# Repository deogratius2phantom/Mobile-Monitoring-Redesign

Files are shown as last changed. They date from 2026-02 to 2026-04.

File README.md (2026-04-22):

# Mobile Air Quality Monitor - Hardware Design

A comprehensive PCB and CAD design for a mobile air quality monitoring system with GPS tracking and cellular connectivity.

## Documentation website

This repository now includes a GitHub Pages documentation site powered by **MkDocs Material**.

- Site source: `docs/`
- Site configuration: `mkdocs.yml`
- Deployment workflow: `.github/workflows/pages.yml`
- Python dependencies for docs work: `requirements-docs.txt`

Once GitHub Pages is enabled for this repository, the published site is expected at:

`https://deogratius2phantom.github.io/Mobile-Monitoring-Redesign/`

### Preview the docs locally

```powershell
python -m pip install -r requirements-docs.txt
python -m mkdocs serve
```

### Build the docs locally

```powershell
python -m mkdocs build --strict
```

## 📋 Project Overview

This repository contains the complete hardware design files for a portable air quality monitoring device. The system is designed to measure environmental air quality parameters while providing real-time GPS location tracking and cellular data transmission capabilities.

## 🔧 Key Features

- **GPS Tracking**: L80-M39 GPS module for precise location tracking
- **Cellular Connectivity**: SIM800L GSM/GPRS module for remote data transmission
- **Modular Design**: Includes daughter board for GPS module
- **Complete PCB Design**: Full KiCad project files with schematics and PCB layouts
- **3D Visualization**: STEP files for mechanical integration and enclosure design

## 📂 Repository Structure

```
├── 3D CAD/                          # 3D CAD files and models
├── L80 GPS daughter board v1/       # GPS module daughter board design files
├── Mobile Monitor Redesign-backups/ # Backup files for KiCad project
├── Mobile Monitor Redesign.kicad_pcb    # Main PCB layout file
├── Mobile Monitor Redesign.kicad_sch    # Main schematic file
├── Mobile Monitor Redesign.kicad_pro    # KiCad project file
├── Mobile Monitor Redesign.step         # 3D model of complete assembly
├── Mobile Monitor Redesign-top.pos      # Top side component positions
├── Mobile Monitor Redesign-bottom.pos   # Bottom side component positions
├── power.kicad_sch                      # Power supply schematic
├── L80-M39--3DModel-STEP-56544.STEP    # GPS module 3D model
├── SIM800L v10.step                     # SIM800L module 3D model
└── report.txt                           # Design report/notes
```

## 🛠️ Tools & Requirements

### Software
- **KiCad 6.0+**: For viewing and editing PCB/schematic files
- **CAD Software**: Any STEP-compatible viewer/editor for 3D models (e.g., FreeCAD, Fusion 360, SolidWorks)

### Hardware Components
- L80-M39 GPS Module
- SIM800L GSM/GPRS Module
- Air quality sensors (see schematic for specific models)
- Power management components (see power.kicad_sch)

## 🚀 Getting Started

### Cloning the Repository

You can clone this repository using either HTTPS or SSH:

#### Option 1: Clone with HTTPS
```bash
git clone https://github.com/deogratius2phantom/Mobile-Monitoring-Redesign.git
cd Mobile-Monitoring-Redesign
```

#### Option 2: Clone with SSH (Recommended for Contributors)
```bash
git clone git@github.com:deogratius2phantom/Mobile-Monitoring-Redesign.git
cd Mobile-Monitoring-Redesign
```

<details>
<summary><b>Setting up SSH for GitHub (Click to expand)</b></summary>

If you haven't set up SSH keys for GitHub yet, follow these steps:

##### 1. Check for Existing SSH Keys
```bash
ls -al ~/.ssh
```
Look for files named `id_rsa.pub`, `id_ecdsa.pub`, or `id_ed25519.pub`.

##### 2. Generate a New SSH Key (if needed)
```bash
ssh-keygen -t ed25519 -C "your_email@example.com"
```
Or if your system doesn't support Ed25519:
```bash
ssh-keygen -t rsa -b 4096 -C "your_email@example.com"
```
Press Enter to accept the default file location, and optionally enter a passphrase.

##### 3. Add SSH Key to SSH Agent
```bash
# Start the SSH agent
eval "$(ssh-agent -s)"

# Add your SSH private key to the agent
ssh-add ~/.ssh/id_ed25519
```
(Replace `id_ed25519` with `id_rsa` if you generated an RSA key)

##### 4. Add SSH Key to Your GitHub Account
```bash
# Copy the SSH public key to clipboard (Linux)
cat ~/.ssh/id_ed25519.pub

# macOS
pbcopy < ~/.ssh/id_ed25519.pub

# Windows (Git Bash)
clip < ~/.ssh/id_ed25519.pub
```

Then:
- Go to GitHub.com and sign in
- Click your profile photo → **Settings**
- In the sidebar, click **SSH and GPG keys**
- Click **New SSH key**
- Add a descriptive title (e.g., "My Laptop")
- Paste your key into the "Key" field
- Click **Add SSH key**

##### 5. Verify SSH Connection to GitHub
```bash
ssh -T git@github.com
```
You should see a message like:
```
Hi username! You've successfully authenticated, but GitHub does not provide shell access.
```

##### 6. Clone the Repository Using SSH
```bash
git clone git@github.com:deogratius2phantom/Mobile-Monitoring-Redesign.git
cd Mobile-Monitoring-Redesign
```

For more detailed information, visit [GitHub's SSH documentation](https://docs.github.com/en/authentication/connecting-to-github-with-ssh).

</details>

### Viewing the Design

1. **Clone the repository** (see above for cloning options)

2. **Open in KiCad**:
   - Launch KiCad
   - Open the project file: `Mobile Monitor Redesign.kicad_pro`
   - View schematics and PCB layout

3. **View 3D Models**:
   - Open `.step` files in your preferred CAD software
   - The main assembly is in `Mobile Monitor Redesign.step`

### Manufacturing the PCB

The repository includes manufacturing-ready files:
- **Gerber files**: Can be generated from the `.kicad_pcb` file
- **BOM (Bill of Materials)**: Extract from schematic
- **Pick-and-place files**: `Mobile Monitor Redesign-top.pos` and `Mobile Monitor Redesign-bottom.pos`

## 📊 Design Specifications

- **PCB Design Tool**: KiCad
- **Layer Count**: [To be specified based on PCB file]
- **GPS Module**: Quectel L80-M39
- **Cellular Module**: SIM800L GSM/GPRS
- **Power Supply**: See `power.kicad_sch` for details

## 📖 Documentation

For detailed information about:
- **Schematic**: Open `Mobile Monitor Redesign.kicad_sch` in KiCad
- **PCB Layout**: Open `Mobile Monitor Redesign.kicad_pcb` in KiCad
- **Power Design**: Reference `power.kicad_sch`
- **Design Notes**: See `report.txt`

For the GitHub Pages site content and structure, see:
- `docs/index.md`
- `docs/getting-started.md`
- `docs/hardware-overview.md`
- `docs/setup-and-first-use.md`
- `docs/operating-the-device.md`
- `docs/troubleshooting.md`
- `docs/safety-and-care.md`
- `docs/maker-and-contributor-reference.md`

## 🤝 Contributing

Contributions to improve the design are welcome! Please:
1. Fork the repository
2. Create a feature branch
3. Make your changes
4. Submit a pull request with detailed description

## ⚠️ Important Notes

- Ensure proper antenna placement for GPS and GSM modules
- Follow power supply guidelines in `power.kicad_sch`
- Verify component footprints before manufacturing
- Test GPS and GSM functionality in your target environment

## 📝 License

[Please specify your license here]

## 📧 Contact

For questions or collaboration opportunities, please open an issue in this repository.

---

**Project Status**: Active Development

*This is a hardware design project for educational and development purposes. Ensure compliance with local regulations for wireless devices before deployment.*

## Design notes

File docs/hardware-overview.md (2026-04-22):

# Hardware Overview

The Mobile Air Quality Monitor is designed as a portable hardware platform for collecting air-quality data while also tracking location and supporting cellular data transmission.

## Main functions

- **Environmental monitoring** through the air-quality sensing hardware defined in the schematic
- **GPS tracking** through the L80-M39 GPS module
- **Cellular connectivity** through the SIM800L GSM/GPRS module
- **Portable deployment** through a compact PCB and enclosure-ready 3D models

## Main design assets in the repository

| Asset | Purpose |
| --- | --- |
| `Mobile Monitor Redesign.kicad_pro` | Main KiCad project entry point |
| `Mobile Monitor Redesign.kicad_sch` | Primary schematic |
| `power.kicad_sch` | Power design details |
| `Mobile Monitor Redesign.kicad_pcb` | PCB layout |
| `Mobile Monitor Redesign.step` | Assembly-level 3D model |
| `L80 GPS daughter board v1/` | GPS daughter-board support files |
| `Mobile Monitor Redesign-top.pos` | Top-side placement data |
| `Mobile Monitor Redesign-bottom.pos` | Bottom-side placement data |

## System blocks

### GPS

The repository references the **Quectel L80-M39** module for positioning. GPS performance will depend on antenna placement, enclosure design, and the final field environment.

### Cellular

The design includes the **SIM800L** GSM/GPRS module for remote communications. Final network setup will depend on your SIM choice, signal quality, and firmware configuration.

### Power

The dedicated `power.kicad_sch` file should be treated as the primary reference for supply-path review, regulator choices, and any bring-up checks before first power.

### Mechanical integration

STEP files in the repository support enclosure work, fit checks, and visual review of the assembled design.

## Current documentation gap

!!! note
    This repository is strongest on design files and weakest on step-by-step product operation. If your team has finalized assembly, provisioning, or field-use procedures, those should be added to this docs site next so end users do not need to reverse-engineer them from KiCad assets.

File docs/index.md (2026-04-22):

# Mobile Air Quality Monitor

This site collects the working documentation for the **Mobile Monitoring Redesign** hardware project. It is intended for two audiences:

- people trying to understand or use the hardware product
- makers and contributors who want to inspect, build, or improve the design

The repository is currently centered on hardware design assets such as KiCad files, STEP models, and manufacturing outputs. This documentation site organizes those materials into a more approachable structure for GitHub Pages.

!!! note
    Some operating details still depend on the final firmware, enclosure, sensor stack, and field workflow used in your build. Where those details are not yet captured in the repository, this site points back to the design files so the documentation can evolve without guessing.

## What this project includes

- a main KiCad project for the mobile monitor PCB
- support files for GPS and GSM modules
- 3D CAD assets for mechanical integration
- placement outputs that can be used during manufacturing

## Start here

If you are new to the project, use this path:

1. Read [Getting Started](getting-started.md) for the quickest way into the design.
2. Review [Hardware Overview](hardware-overview.md) to understand the major modules.
3. Use [Setup and First Use](setup-and-first-use.md) before powering a build or opening the design files.
4. Keep [Troubleshooting](troubleshooting.md) and [Safety and Care](safety-and-care.md) handy during testing.

If you are contributing to the project, jump to [Maker and Contributor Reference](maker-and-contributor-reference.md).

## Documentation scope

This first version of the docs site is focused on:

- turning the repository into a browsable GitHub Pages site
- documenting how to navigate and use the hardware design package
- establishing a place for future end-user instructions as the product matures

## Source of truth

The most detailed technical artifacts still live in the repository root:

- `Mobile Monitor Redesign.kicad_pro`
- `Mobile Monitor Redesign.kicad_sch`
- `Mobile Monitor Redesign.kicad_pcb`
- `power.kicad_sch`
- `Mobile Monitor Redesign.step`
- `report.txt`

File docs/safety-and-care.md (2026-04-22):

# Safety and Care

This repository contains a hardware design for a mobile monitoring device with radio modules and power circuitry. Treat prototypes and assembled boards with the same care you would give any RF-enabled electronics project.

## Handling

- Protect the board from electrostatic discharge during assembly and inspection.
- Avoid flexing the PCB when modules, headers, or antenna connectors are installed.
- Keep conductive debris away from exposed electronics and test fixtures.

## Power precautions

- Verify voltage, polarity, and current capability before first power.
- If your build uses a rechargeable battery, use charging and protection circuitry appropriate to that chemistry.
- Do not leave early prototypes unattended while verifying first power or GSM transmit behavior.

## RF and antenna considerations

- Follow local regulations for wireless devices and SIM-based connectivity.
- Keep antennas clear of large metal obstructions and enclosure features that may reduce performance.
- Avoid unnecessary handling of the antenna path while the device is operating.

## Environmental care

- Protect the device from moisture, contamination, and extreme temperatures unless your enclosure and sensor choices are designed for that environment.
- If the project is deployed outdoors, validate enclosure sealing and venting before field use.

## Storage and transport

- Store boards and modules in anti-static packaging when possible.
- Secure loose antennas, cables, and daughter boards before transport.
- Label test units clearly so unfinished prototypes are not mistaken for fully validated hardware.

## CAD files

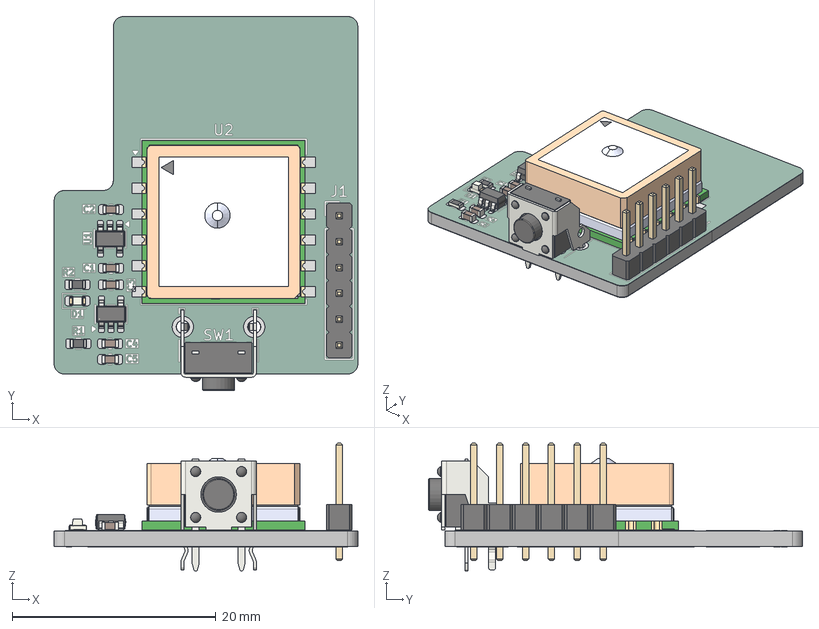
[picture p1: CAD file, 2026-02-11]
L80 GPS daughter board v1/L80 GPS daughter board v1.step
29.8 x 36.7 x 12.5 mm
C_0603_1608Metric x 5
R_0603_1608Metric x 2
L80-M39--3DModel-STEP-56544
LED_0603_1608Metric
SW_Tactile_SPST_Angled_PTS645Vx39-2LFS
SOT-23-5 x 2
PinHeader_1x06_P2.54mm_Vertical
L80 GPS daughter board v1_copper
L80 GPS daughter board v1_pad
L80 GPS daughter board v1_via
L80 GPS daughter board v1_silkscreen
L80 GPS daughter board v1_soldermask x 2
L80 GPS daughter board v1_PCB

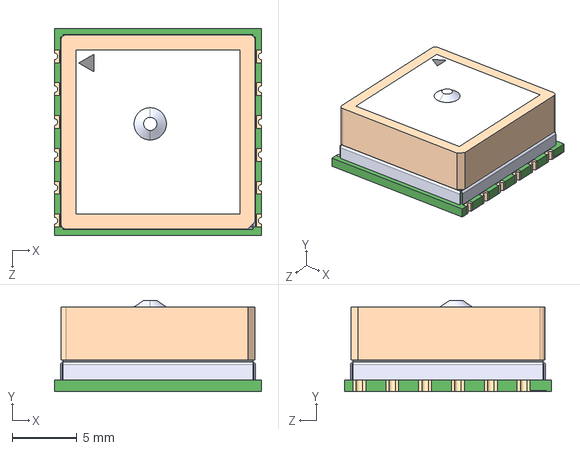
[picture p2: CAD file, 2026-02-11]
L80-M39--3DModel-STEP-56544.STEP
16.0 x 7.05 x 16.0 mm

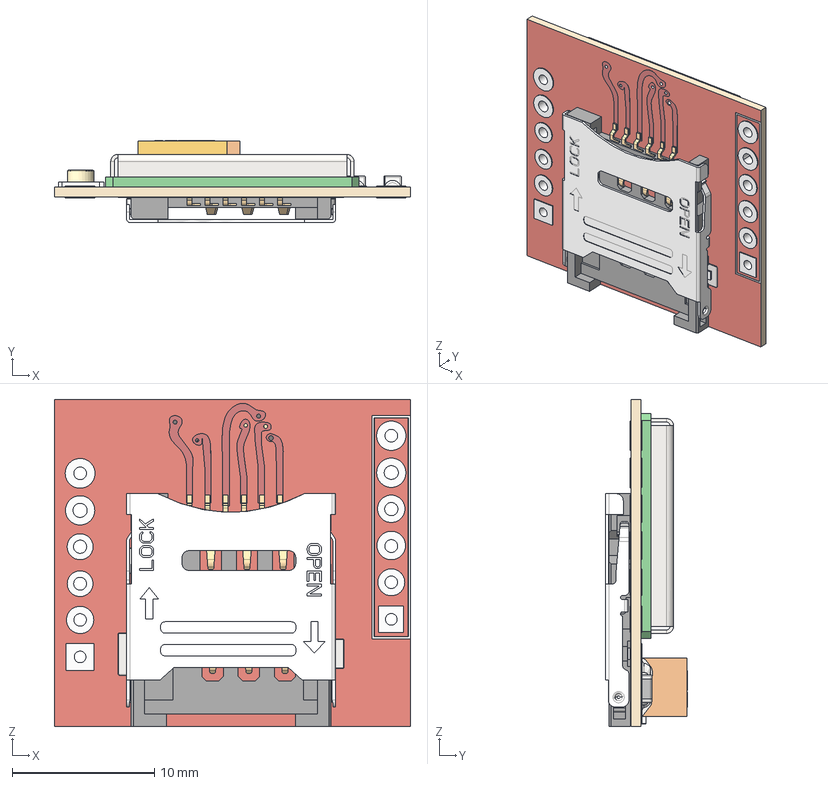
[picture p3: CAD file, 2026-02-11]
SIM800L v10.step
25.0 x 5.77 x 23.0 mm
PCB
Cage
CH03-HB

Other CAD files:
3D CAD/enclosure base.SLDPRT
L80 GPS daughter board v1/L_APV_APH1040_1.step.SLDPRT

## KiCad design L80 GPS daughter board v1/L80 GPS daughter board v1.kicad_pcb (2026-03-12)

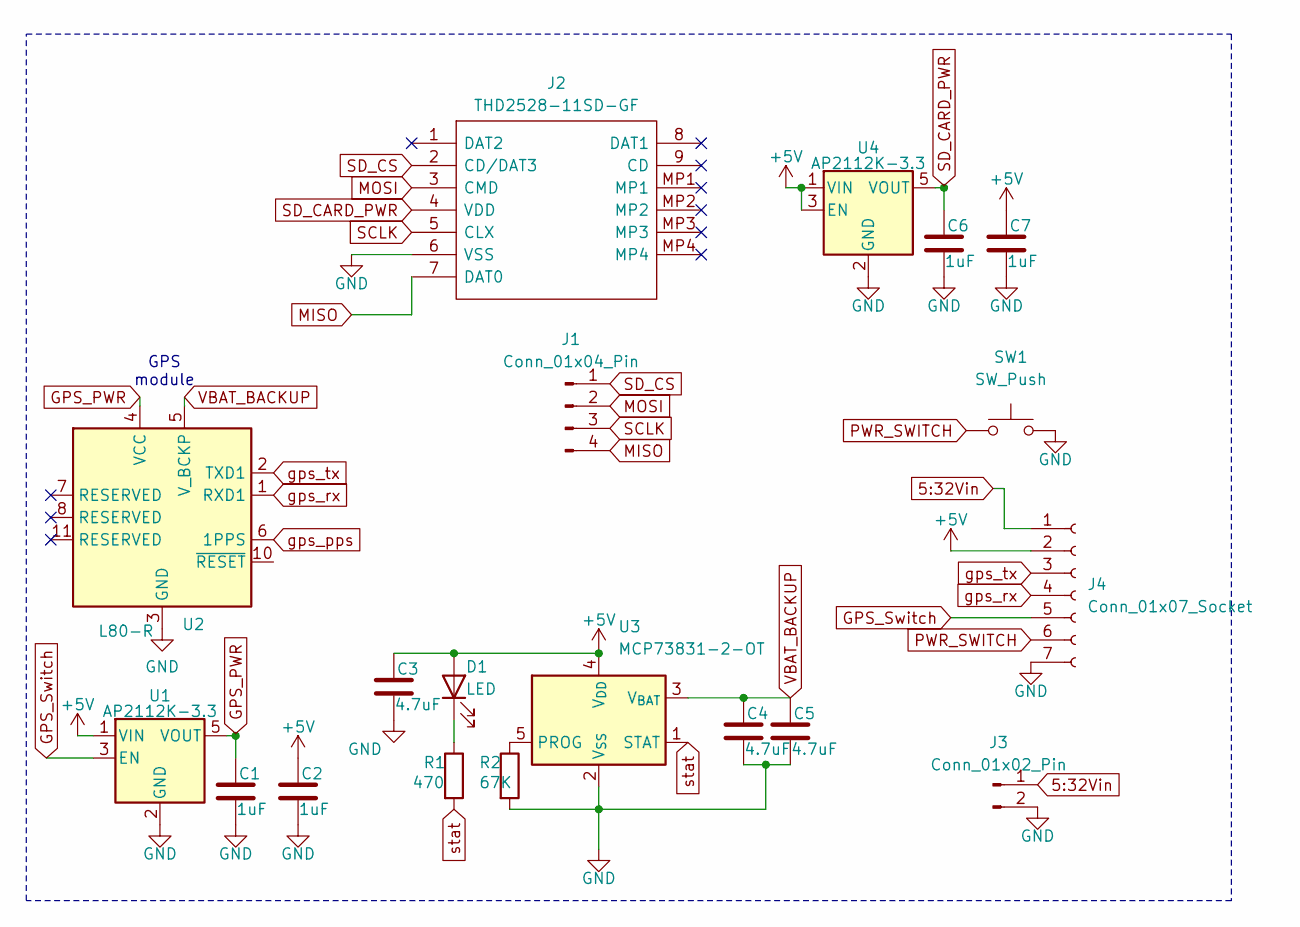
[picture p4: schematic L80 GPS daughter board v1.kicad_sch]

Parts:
C1, C2, C6, C7: 1uF; C_0603_1608Metric
C3, C4, C5: 4.7uF; C_0603_1608Metric
D1: LED; LED_0603_1608Metric
J1: Conn_01x04_Pin; PinHeader_1x04_P2.00mm_Vertical_SMD_Pin1Left
J2: THD2528-11SD-GF; THD252811SDGF; Manufacturer_Part_Number THD2528-11SD-GF
J3: Conn_01x02_Pin; PinHeader_1x02_P2.54mm_Vertical
J4: Conn_01x07_Socket; PinSocket_1x07_P2.54mm_Vertical
R1: 470; R_0603_1608Metric
R2: 67K; R_0603_1608Metric
SW1: SW_Push; SW_Tactile_SPST_Angled_PTS645Vx39-2LFS
U1, U4: AP2112K-3.3; SOT-23-5
U2: L80-R; Quectel_L80-R
U3: MCP73831-2-OT; SOT-23-5

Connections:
5:32Vin: J3.1, J4.1
+5V: C2.1, C3.1, C7.1, D1.2 (A), J4.2, U1.1 (VIN), U3.4 (V_{DD}), U4.1 (VIN), U4.3 (EN)
GND: C1.2, C2.2, C3.2, C4.2, C5.2, C6.2, C7.2, J2.6 (VSS), J3.2, J4.7, R2.2, SW1.2, U1.2 (GND), U2.3 (GND), U2.12 (GND), U3.2 (V_{SS}), U4.2 (GND)
GPS_PWR: C1.1, U1.5 (VOUT), U2.4 (VCC)
GPS_Switch: J4.5, U1.3 (EN)
MISO: J1.4, J2.7 (DAT0)
MOSI: J1.2, J2.3 (CMD)
unnamed: D1.1 (K), R1.1
unnamed: R2.1, U3.5 (PROG)
PWR_SWITCH: J4.6, SW1.1
SCLK: J1.3, J2.5 (CLX)
SD_CARD_PWR: C6.1, J2.4 (VDD), U4.5 (VOUT)
SD_CS: J1.1, J2.2 (CD/DAT3)
VBAT_BACKUP: C4.1, C5.1, U2.5 (V_BCKP), U3.3 (V_{BAT})
gps_pps: U2.6 (1PPS)
gps_rx: J4.4, U2.1 (RXD1)
gps_tx: J4.3, U2.2 (TXD1)
stat: R1.2, U3.1 (STAT)

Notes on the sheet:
GPS module

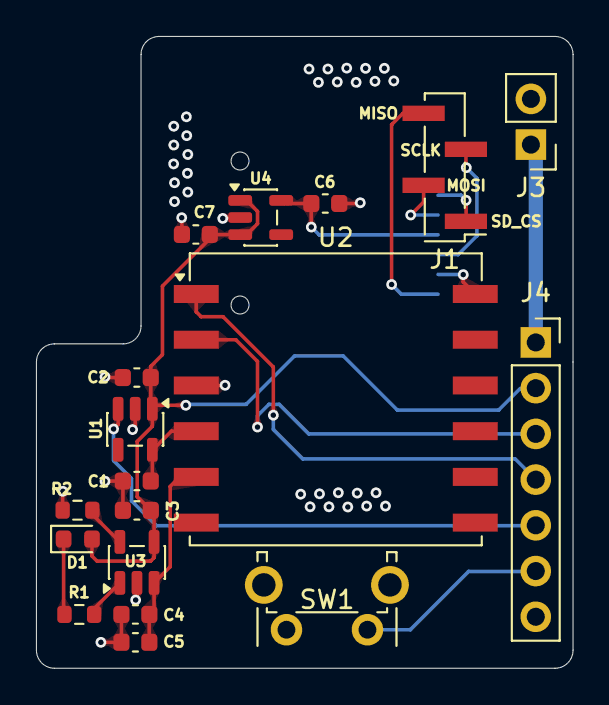
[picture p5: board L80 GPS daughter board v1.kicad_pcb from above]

Board: 4 copper layers, 29.8 x 35.1 mm, 19 parts (1 on the bottom side), 17 nets.

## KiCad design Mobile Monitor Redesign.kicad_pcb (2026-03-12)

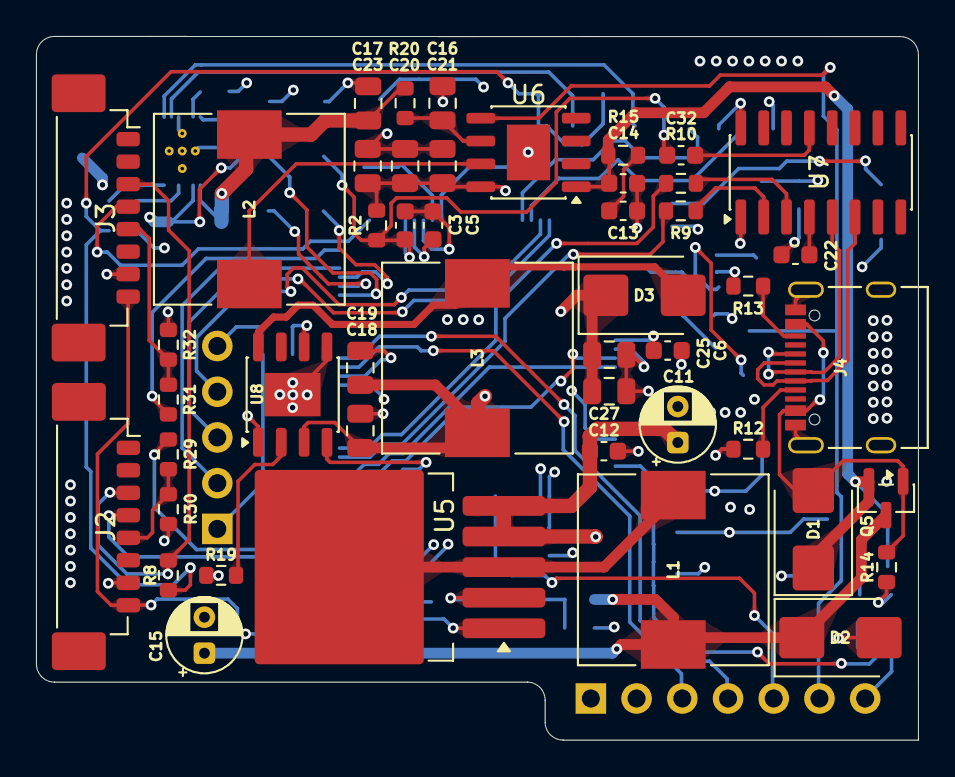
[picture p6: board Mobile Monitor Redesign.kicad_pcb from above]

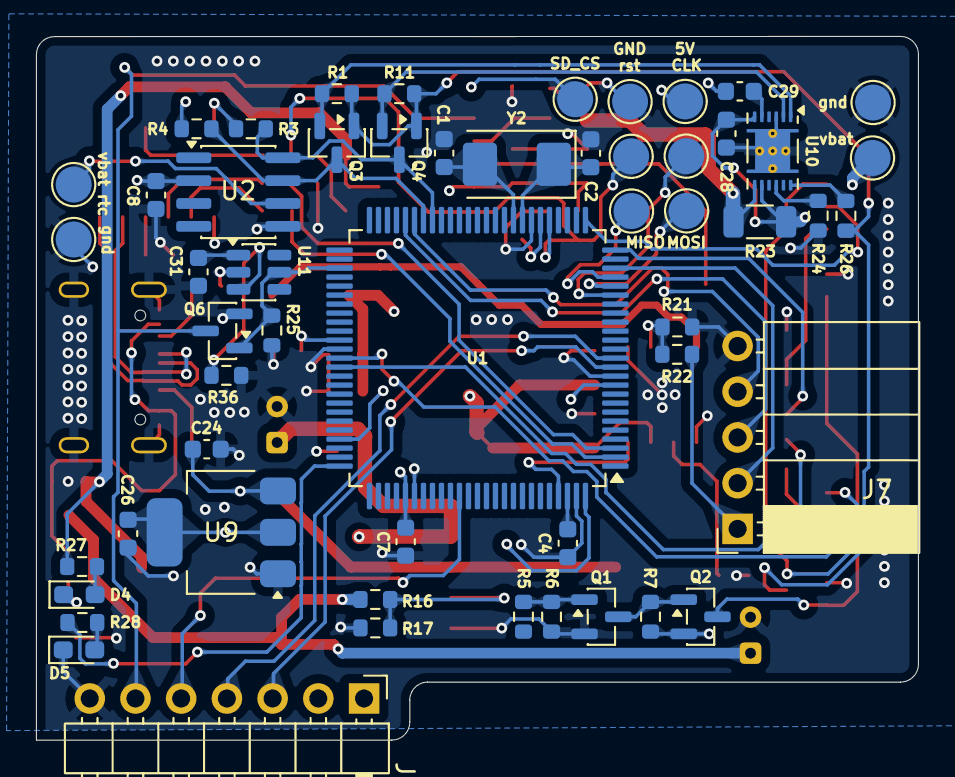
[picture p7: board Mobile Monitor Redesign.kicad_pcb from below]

Board: 4 copper layers, 49.0 x 39.1 mm, 101 parts (54 on the bottom side), 68 nets.

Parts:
5V: TestPoint_Pad_D2.0mm
C1, C2, C4, C5, C6, C7, C32: 100nF; C_0603_1608Metric
C3: 22p; C_0603_1608Metric
C8, C22: 1UF; C_0603_1608Metric
C11, C15: 470UF; CP_Radial_D4.0mm_P2.00mm
C12: 0.1UF; C_0603_1608Metric
C13, C14: 10uF; C_0603_1608Metric
C16, C17, C18, C19, C20, C21, C23, C25, C27: 22uF; C_0805_2012Metric
C24, C26, C28, C31: 1uF; C_0603_1608Metric
C29: 0.47uF; C_0603_1608Metric
CLK: TestPoint_Pad_D2.0mm
D1, D2, D3: SK54B; D_SMB
D4, D5: LED; LED_0603_1608Metric_Pad1.05x0.95mm_HandSolder
GND: TestPoint_Pad_D2.0mm
J2, J3: Conn_01x08_Pin; Molex_PicoBlade_53398-0871_1x08-1MP_P1.25mm_Vertical
J4: USB_C_Receptacle_USB2.0_16P; USB_C_Receptacle_Palconn_UTC16-G
J7: Conn_01x05_Pin; PinSocket_1x05_P2.54mm_Horizontal
J9: Conn_01x07_Socket; PinHeader_1x07_P2.54mm_Horizontal
L1, L3: 33uH; L_10.4x10.4_H4.8
L2: 1uH; L_10.4x10.4_H4.8
MISO: TestPoint_Pad_D2.0mm
MOSI: TestPoint_Pad_D2.0mm
Q1, Q6: 2N7002; SOT-23
Q2, Q5: AO3401A; SOT-23
Q3, Q4: BSS138; SOT-23
R1, R2, R3, R4, R7, R8, R11, R24, R25, R26: 10K; R_0603_1608Metric
R5, R9, R10, R27, R28, R29, R31: 1K; R_0603_1608Metric
R6, R36: 4.7K; R_0603_1608Metric
R12, R13: 5.1K; R_0603_1608Metric
R14: 100K; R_0603_1608Metric
R15: 2; R_0603_1608Metric
R16: 10.5K; R_0603_1608Metric
R17, R30, R32: 2K; R_0603_1608Metric
R19: 26k; R_0603_1608Metric
R20: 0.5; R_0603_1608Metric
R21: 59k; R_0603_1608Metric
R22: 10k; R_0603_1608Metric
R23: 0.01; R_1206_3216Metric
SD_CS: TestPoint_Pad_D2.0mm
U1: ATmega2560-16A; TQFP-100_14x14mm_P0.5mm
U2: DS3232M; SOIC-8_3.9x4.9mm_P1.27mm
U5: XL4005; TO-263-5_TabPin3
U6: IP5306; HSOP-8-1EP_3.9x4.9mm_P1.27mm_EP2.41x3.1mm
U7: CH340C; SOIC-16_3.9x9.9mm_P1.27mm
U8: FP6298XR; HSOP-8-1EP_3.9x4.9mm_P1.27mm_EP2.41x3.1mm
U9: AMS1117-3.3; SOT-223-3_TabPin2
U10: BQ27441DRZR-G1A; Texas_S-PDSO-N12
U11: TPL5010; SOT-23-6
Y2: Crystal; Crystal_SMD_Abracon_ABM3-2Pin_5.0x3.2mm
gnd: TestPoint_Pad_D2.0mm
gnd#2: TestPoint_Pad_D2.0mm
rst: TestPoint_Pad_D2.0mm
vbat: TestPoint_Pad_D2.0mm
vbat rtc: TestPoint_Pad_D2.0mm

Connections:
5:32V DC INPUT: C11.1, C12.1, J9.1, U5.4 (EN), U5.5 (VIN)
+3.3V: C26.1, Q3.1 (G), Q4.1 (G), R1.2, R8.2, R11.2, R26.1, U9.2 (VO)
+5V: 5V.1, C5.1, C6.1, C7.1, C8.1, C20.1, C21.1, C23.1, C24.1, J9.2, Q2.2 (S), R2.2, R3.2, R4.2, R7.2, U1.10 (VCC), U1.31 (VCC), U1.61 (VCC), U1.80 (VCC), U1.100 (AVCC), U2.2 (VCC), U6.8 (VOUT), U7.16 (VCC), U9.3 (VI)
/BATTERY_SEC: C31.1, U11.1 (VDD)
/power/5V Regulated: C15.1, D2.1 (K), L1.2, Q5.3 (D), R16.1
/power/5VSW: L1.1, U5.3 (SW)
/power/BATTERY_PRIMARY: C28.1, R23.2, U10.6 (BAT), U10.8 (SRP), vbat.1
/power/BATTERY_SEC: C17.1, C18.1, C19.1, L2.2, L3.1, R20.2, R23.1, U8.3 (VCC), U10.7 (SRN)
/power/FB: R21.1, R22.2, U8.6 (FB)
/power/VBUS_PRIMARY: D1.2 (A), J4.A4 (VBUS), J4.A9 (VBUS), J4.B4 (VBUS), J4.B9 (VBUS), Q5.1 (G), R14.2
ADJUSTABLE_GSM_PWR_4.2: C25.1, C27.1, D3.1 (K), J7.1, R21.2
CC1: J4.A5 (CC1), R12.1
CC2: J4.B5 (CC2), R13.1
D+: J4.A6 (D+), J4.B6 (D+), U7.5 (UD+)
D-: J4.A7 (D-), J4.B7 (D-), U7.6 (UD-)
GND: C1.2, C2.1, C3.2, C4.2, C5.2, C6.2, C7.2, C8.2, C11.2, C12.2, C13.2, C14.2, C15.2, C16.2, C17.2, C18.2, C19.2, C20.2, C21.2, C22.2, C23.2, C24.2, C25.2, C26.2, C27.2, C28.2, C29.2, C31.2, D2.2 (A), D4.1 (K), D5.1 (K), GND.1, J2.7, J3.7, J4.A1 (GND), J4.A12 (GND), J4.B1 (GND), J4.B12 (GND), J4.S1 (SHIELD), J7.5, J9.7, Q1.2 (S), Q6.2 (S), R6.1, R12.2, R13.2, R14.1, R17.2, R19.1, R22.1, R24.1, R25.1, R30.1, R32.1, R36.1, U1.11 (GND), U1.32 (GND), U1.62 (GND), U1.81 (GND), U1.99 (GND), U2.5 (GND), U5.1 (GND), U6.9 (GND), U7.1 (GND), U8.1 (PGND), U8.5 (GND), U8.9 (ep), U9.1 (GND), U10.3 (V_{SS}), U10.13 (PAD), U11.2 (GND), gnd.1, gnd#2.1
GPS_Switch: J9.5, U1.86 (PK3)
GSM_PWR_EN: U1.97 (PF0), U8.4 (EN)
GSM/RESET: J7.2, U1.23 (PB4)
unnamed: C13.1, R15.1
unnamed: D3.2 (A), L3.2, U8.8 (LX)
unnamed: D4.2 (A), R27.1
unnamed: D5.2 (A), R28.2
unnamed: Q1.3 (D), Q2.1 (G), R7.1
unnamed: Q1.1 (G), R5.1, R6.2
unnamed: C4.1, U1.98 (AREF)
unnamed: C1.1, U1.34 (XTAL1), Y2.2
unnamed: C2.2, U1.33 (XTAL2), Y2.1
unnamed: R16.2, R17.1, U5.2 (FB)
unnamed: C16.1, R20.1, U6.6 (BAT)
unnamed: L2.1, U6.7 (SW)
unnamed: R10.1, U7.3 (RXD)
unnamed: R9.1, U7.2 (TXD)
unnamed: C22.1, U7.4 (V3)
unnamed: C32.1, U7.13 (~DTR)
unnamed: R19.2, U8.2 (OC)
unnamed: R24.2, U10.10 (BIN)
unnamed: R26.2, U10.12 (GPOUT)
unnamed: C29.1, U10.5 (V_{DD})
unnamed: R36.2, U11.3 (DELAY/M_RST)
PMS_RX: J3.4, U1.26 (PB7)
PMS_TX: R31.2, U1.25 (PB6)
PWR_SWITCH: J9.6, Q6.3 (D), U6.5 (KEY)
RESET: C3.1, C32.2, R2.1, U1.30 (~RESET), rst.1
RXD0: R9.2, U1.2 (PE0)
RXD1: J7.4, U1.45 (PD2)
RXD2: J9.3, U1.12 (PH0)
RXD3: J2.4, U1.63 (PJ0)
SCL: Q4.3 (D), R3.1, U1.43 (PD0), U2.8 (SCL)
SCL_3.3: Q4.2 (S), R11.1, U10.2 (SCL)
SDA: Q3.3 (D), R4.1, U1.44 (PD1), U2.7 (SDA)
SDA_3.3: Q3.2 (S), R1.1, U10.1 (SDA)
SD_CHIP_SELECT/D28: SD_CS.1, U1.72 (PA6)
SENSOR_1_RX: J2.5, R29.1, R30.2
SENSOR_2_RX: J3.5, R31.1, R32.2
SENSOR_PWR: J2.8, J3.8, Q2.3 (D)
SENSOR_RESET: J2.3, J3.3, R8.1
SOFT_PWR_SWITCH: Q6.1 (G), R25.2, U1.53 (PC0), U11.5 (WAKE)
SPI/CLK: CLK.1, U1.20 (PB1)
SPI/MISO: MISO.1, U1.22 (PB3)
SPI/MOSI: MOSI.1, U1.21 (PB2)
TXD0: R10.2, U1.3 (PE1)
TXD1: J7.3, U1.46 (PD3)
TXD2: J9.4, U1.13 (PH1)
TXD3: R29.2, U1.64 (PJ1)
VBAT_RTC: U2.6 (VBAT), vbat rtc.1
VIN: C14.1, D1.1 (K), Q5.2 (S), R15.2, R27.2, U6.1 (VIN)
status_led: R28.1, U1.75 (PA3)

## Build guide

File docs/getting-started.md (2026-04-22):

# Getting Started

This project documents a portable air-quality monitor design with onboard GPS and cellular connectivity. The repository can be used in three different ways depending on your goals.

## Choose your starting point

| Goal | Best place to start |
| --- | --- |
| Understand what the hardware does | [Hardware Overview](hardware-overview.md) |
| Review or modify the design | [Maker and Contributor Reference](maker-and-contributor-reference.md) |
| Prepare to assemble, inspect, or power a build | [Setup and First Use](setup-and-first-use.md) |

## What you need

### To read the documentation site

- a web browser
- access to the GitHub repository or published GitHub Pages site

### To inspect the hardware design

- **KiCad 6.0+** for the schematic and PCB files
- a STEP-compatible CAD viewer if you want to inspect the mechanical models

### To contribute to the docs

- Python 3
- the packages in `requirements-docs.txt`

```powershell
python -m pip install -r requirements-docs.txt
python -m mkdocs serve
```

The local preview server will show the documentation site and reload changes as you edit files in `docs/`.

## Repository quick start

Clone the repository:

```powershell
git clone https://github.com/deogratius2phantom/Mobile-Monitoring-Redesign.git
cd Mobile-Monitoring-Redesign
```

If you contribute regularly, you can also use the SSH URL once your GitHub SSH key is configured.

## What is currently documented

The repository already includes:

- project-level hardware context in `README.md`
- manufacturing and placement artifacts in the repository root
- design notes in `report.txt`

The GitHub Pages site builds on that material and provides a clearer navigation structure for future product-usage documentation.

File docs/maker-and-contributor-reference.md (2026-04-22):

# Maker and Contributor Reference

This section is for the general maker community and for contributors who want to inspect, modify, document, or manufacture the design.

## Repository layout

| Path | Contents |
| --- | --- |
| `3D CAD/` | Mechanical CAD files |
| `L80 GPS daughter board v1/` | GPS daughter-board design assets |
| `Mobile Monitor Redesign.kicad_pro` | KiCad project file |
| `Mobile Monitor Redesign.kicad_sch` | Main schematic |
| `Mobile Monitor Redesign.kicad_pcb` | Main PCB layout |
| `Mobile Monitor Redesign.step` | Assembly-level STEP model |
| `Mobile Monitor Redesign-top.pos` | Top-side placement file |
| `Mobile Monitor Redesign-bottom.pos` | Bottom-side placement file |
| `power.kicad_sch` | Power schematic |
| `report.txt` | Design notes |

## Working with the design

### KiCad

Open `Mobile Monitor Redesign.kicad_pro` in KiCad 6.0 or newer. Use the project view so schematic sheets, board data, and linked assets resolve together.

### 3D review

Use the STEP models to check fit, enclosure constraints, and module placement before manufacturing changes.

### Manufacturing review

The repository already includes pick-and-place outputs:

- `Mobile Monitor Redesign-top.pos`
- `Mobile Monitor Redesign-bottom.pos`

Use them alongside the PCB and schematic data when preparing fabrication outputs or contract manufacturing packages.

## Documentation workflow

The GitHub Pages site is built with MkDocs Material.

### Files you will edit

- `mkdocs.yml` for navigation and site configuration
- `docs/` for Markdown content
- `.github/workflows/pages.yml` for deployment automation

### Local preview

```powershell
python -m pip install -r requirements-docs.txt
python -m mkdocs serve
```

### Production build

```powershell
python -m mkdocs build --strict
```

## Publishing

The Pages workflow builds the site on pushes to `main` or `master` and deploys the generated `site/` output through GitHub Actions. In the repository settings, GitHub Pages should be configured to use **GitHub Actions** as the source.

## Good next additions

High-value future documentation for this project would include:

- a bill of materials page
- firmware or data-pipeline setup instructions
- field deployment examples
- assembly photos and enclosure guidance
- final end-user operating procedures

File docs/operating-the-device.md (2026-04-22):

# Operating the Device

The repository does not yet include a finalized end-user operating manual, but the intended workflow for the hardware is clear from the project structure: power the unit, acquire sensor data, associate that data with location, and transmit or log results for later review.

## Expected usage flow

1. Prepare the device with the correct power source, installed modules, and any required firmware.
2. Move the unit to an environment suitable for both sensor readings and GPS reception.
3. Power on the hardware and allow time for the system to stabilize.
4. Confirm that the GPS and cellular subsystems behave as expected for your build.
5. Start the measurement or logging process defined by your firmware stack.
6. Review captured data, then power down the device safely.

## What operators should watch

### Power stability

Unexpected resets, brownouts, or module dropouts often point back to the power design or the chosen test supply. Review `power.kicad_sch` if system behavior looks unstable under load.

### GPS readiness

GPS modules typically need time, open sky, and good antenna placement to achieve a stable lock. Indoor testing can make normal acquisition look like a fault.

### Cellular readiness

The SIM800L portion of the design will depend on network coverage, SIM provisioning, and firmware configuration. If remote data upload is part of your workflow, record those assumptions during test setup.

### Sensor interpretation

The exact air-quality sensor operating sequence is not yet documented in the repository. If your build includes a known sensor stack and calibration procedure, that information should be added here in a later revision.

## Suggested next documentation additions

To turn this into a complete user guide, add:

- the final power-up sequence
- status indicators or expected serial output
- sensor warm-up guidance
- data export or dashboard access steps
- shutdown and storage guidance for the finished product

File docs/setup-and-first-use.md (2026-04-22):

# Setup and First Use

This page is written for both early hardware evaluators and makers preparing a build from the design files.

## Before first power

Use this checklist before connecting power to a board or reviewing a newly assembled unit:

1. Confirm that the PCB assembly matches the latest schematic and layout in the repository.
2. Review the power path in `power.kicad_sch` and verify expected input voltage, polarity, and regulator orientation.
3. Check GPS and GSM module placement, connector orientation, and antenna clearances.
4. Inspect solder joints, rework areas, and any hand-fitted modules before power-up.
5. Make sure your test environment is appropriate for RF bring-up and GPS reception.

## If you are starting from the design files

1. Open `Mobile Monitor Redesign.kicad_pro` in KiCad.
2. Review the main schematic and the separate power schematic together.
3. Inspect `Mobile Monitor Redesign.kicad_pcb` for placement, routing, and board constraints.
4. Open the STEP files if you need a mechanical fit or enclosure check.
5. Use the `.pos` files when preparing pick-and-place or assembly review tasks.

## If you are starting from a built unit

The exact first-use flow depends on the firmware and sensor configuration loaded on the hardware. At a minimum, capture the following for your build notes:

- power source used for testing
- installed SIM or connectivity setup
- expected sensor population
- intended data logging or upload behavior
- enclosure or antenna configuration

## Recommended bring-up record

For repeatable testing, keep a short bring-up log with:

- board revision or assembly identifier
- date and test location
- GPS lock status
- cellular registration status
- observed power behavior
- any missing sensors or optional modules

That record will make future troubleshooting and documentation updates much easier.

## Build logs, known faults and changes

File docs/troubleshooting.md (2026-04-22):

# Troubleshooting

Use this page as a starting point when the design files open correctly but the hardware or bring-up workflow does not behave as expected.

## No power or unstable power

Check:

- input voltage and polarity
- regulator orientation and solder quality
- shorts or bridges around the power section
- high current draw from GSM activity

Reference: `power.kicad_sch`

## GPS does not lock

Check:

- antenna placement and grounding constraints
- outdoor or window-adjacent testing conditions
- module orientation and footprint alignment
- whether the build has enough startup time for acquisition

Reference: the L80-M39 design assets and main schematic

## Cellular link does not come up

Check:

- SIM installation and activation status
- antenna connection and placement
- power stability during transmit bursts
- firmware settings for baud rate, APN, and network registration

Reference: SIM800L model files and the main schematic

## Design files do not open as expected

Check:

- KiCad version compatibility
- missing project-relative assets
- whether you opened the `.kicad_pro` file rather than an individual file in isolation

## Placement or manufacturing outputs look wrong

Check:

- that you are using the latest `.pos` files from the repository root
- component origin and rotation settings in your assembly workflow
- whether assembly outputs match the PCB revision you intend to build

## When to escalate

If a problem cannot be isolated from the files in this repository, document:

- the exact board revision or file revision
- the power source used
- observed GPS and cellular behavior
- screenshots or export files from KiCad if layout review is involved

That information will make issue reports and future documentation updates much more useful.

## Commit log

2026-01-27 started working on the L80 GPS carrier board
    [L80 GPS daughter board v1.kicad_pcb]
2026-02-06 cleaned up more routing and component placement
    [Mobile Monitor Redesign.kicad_pcb, Mobile Monitor Redesign.kicad_sch, power.kicad_sch]
2026-02-09 routed the l80 gps daughter board and a few more modifications
    [L80 GPS daughter board v1.kicad_pcb, L80 GPS daughter board v1.kicad_sch, Mobile Monitor Redesign.kicad_pcb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]
2026-02-10 updated routing and placement of devices on both PCBS
    [L80 GPS daughter board v1.kicad_pcb, L80 GPS daughter board v1.step, Mobile Monitor Redesign.kicad_pcb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]
2026-02-10 cleaned up routes and added pads for SPI connections
    [CP_Radial_D4.0mm_P2.00mm_1.step.SLDPRT, C_0603_1608Metric_1.step.SLDPRT, C_0805_2012Metric_1.step.SLDPRT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]
2026-02-11 adjusted file locations of some 3d models so that the project is fully localized
    [L80 GPS daughter board v1.kicad_pcb, L80.stp, Mobile Monitor Redesign.kicad_pcb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]
2026-02-11 started on the enclosure designs
    started on the enclosure designs
    [L80 GPS daughter board v1.kicad_pcb, L80 GPS daughter board v1.kicad_sch, L80 GPS daughter board v1.step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]
2026-02-11 rectified file paths for L80 3d m odel
    [L80 GPS daughter board v1.kicad_pcb]
2026-02-19 added 3.3v logic level shifting for battery monitoring chip I2C lines
    [power.kicad_sch]
2026-02-20 fixed some DRC errors and cleaned up routing
    [Mobile Monitor Redesign.kicad_pcb]
2026-03-11 adjsuted placment in pcb design
    [Mobile Monitor Redesign.kicad_pcb]
2026-03-12 added another pin for power connection
    [Mobile Monitor Redesign.kicad_pcb, Mobile Monitor Redesign.kicad_sch, power.kicad_sch]
2026-03-12 modefied gps board to handle sdcard operations and power input
    [L80 GPS daughter board v1.kicad_pcb]
2026-03-12 added SD card pinout
    [L80 GPS daughter board v1.kicad_pcb, L80 GPS daughter board v1.kicad_sch]
2026-03-12 cleaned up sd card routing and added appropriate connectors
    [L80 GPS daughter board v1.kicad_pcb, L80 GPS daughter board v1.kicad_sch]
2026-03-12 removed redundant SD-card schematic on base PCB
    [Mobile Monitor Redesign.kicad_pcb, Mobile Monitor Redesign.kicad_sch]
2026-03-12 recheked gps serial pin mappings
    [Mobile Monitor Redesign.kicad_pcb, Mobile Monitor Redesign.kicad_sch]
2026-03-12 modefied gps board pins
    [L80 GPS daughter board v1.kicad_pcb, L80 GPS daughter board v1.kicad_sch]
